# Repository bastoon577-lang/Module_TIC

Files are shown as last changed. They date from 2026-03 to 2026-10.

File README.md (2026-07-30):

<p align="center">
  <!-- Ko-fi badge -->
  <a href="https://Ko-fi.com/bastoon577lang">
    
  </a>

  <!-- Buy Me a Coffee badge -->
  <a href="https://buymeacoffee.com/bastoon577lang">
    
  </a>

  <!-- PayPal badge -->
  <a href="https://www.paypal.com/donate?hosted_button_id=4CDVJA8LLUR78">
    
  </a>
</p>

# Module_TIC
Le Module TIC est un équippement fonctionnant sur plateforme [ESP01](https://www.captain-arduino.fr/esp8266-01s/) capable d'extraire les données issues du bornier TIC du compteur Linky et de les partager/offrir
sur un réseau TCP/IP au travers du WIFI et d'un mécanisme WebSocket.

<div align="center">
  <picture>
    ModuleTIC
  </picture>
</div>

*******
Table des matières
 1. [Mes motivations](#motivation)
 2. [Concept du Module TIC ?](#concept)
 3. [Notice d'utilisation](#useit)
 4. [Reproduction hardware](#hard)
*******

<div id='motivation'/> 

## Mes motivations
Aveugle sur la consommation d'énergie de mon foyer, j'ai souhaité intégrer un mécanisme capable de lire en temps réel les données issues du compteur Linky.
Le but étant par la suite d'effectuer l'asservissement des équipements en foncton de l'énergie disponible de l'installation électrique par le délestage :
 1. De la charge de la voiture électrique,
 2. Du ballon d'eau chaude,
 3. De Miner de bitcoin,
 4. etc...

<div id='concept'/> 

## Concept du Module TIC
Veuillez consulter le [Wiki du projet](https://github.com/bastoon577-lang/Module_TIC/wiki) pour plus d'informations concernant le concept.

<div id='useit'/> 

## Notice d'utilisation
Veuillez consulter la [notice d'utilisation](https://github.com/bastoon577-lang/Module_TIC/blob/main/USER_MANUAL/Notice%20Module%20TIC.pdf) pour plus d'informations.

<div id='hard'/>

## Reproduction hardware

J'ai mis à disposition les sources complètes (BOM, GERBER, etc.) pour la reproduction du PCB ModuleTIC [ici](https://oshwlab.com/sebastiendaligault577/module-tic) que j'ai fait imprimé chez [JLCPCB](https://jlcpcb.com/fr/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).

J'ai du matériel à disposition [ici](https://github.com/bastoon577-lang/Module_TIC/wiki/Fourniture-Hardware) 😉
 
 ###### Auteur : *Sébastien DALIGAULT*.

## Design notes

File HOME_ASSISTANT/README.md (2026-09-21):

# Configurations

> ⚠️ Il existe différents modes de fonctionnement:
> * Le mode Historique (Monophasé ou Triphasés)
> * Le mode Standard (Monophasé ou Triphasés)

## Mode Historique

Utilisez le fichier [Mode_Historique.yml](https://github.com/bastoon577-lang/Module_TIC/blob/main/HOME_ASSISTANT/Mode_Historique.yml)
puis ajoutez/supprimez les données que vous souhaitez remonter en consultant la documentation technique Enedis-MOP-CPT_002E-1.pdf.

## Mode Standard

Utilisez le fichier [Mode_Standard.yml](https://github.com/bastoon577-lang/Module_TIC/blob/main/HOME_ASSISTANT/Mode_Standard.yml)
puis ajoutez/supprimez les données que vous souhaitez remonter en consultant la documentation technique Enedis-MOP-CPT_002E-1.pdf.

#### Auteur : *Sébastien DALIGAULT*.

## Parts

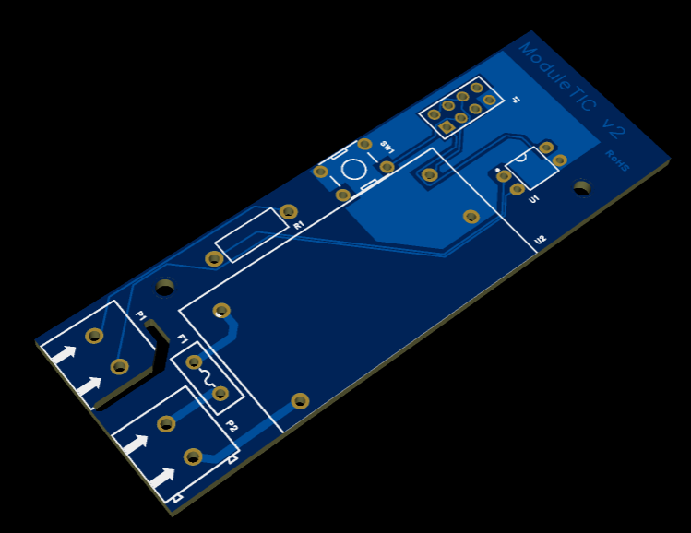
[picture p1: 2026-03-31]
HARDWARE/PCB/PCB_3D_WITHOUT_COMPONENTS.png

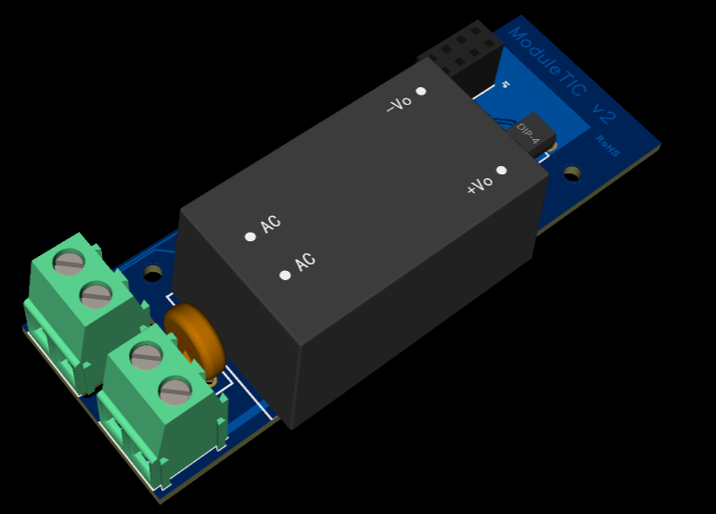
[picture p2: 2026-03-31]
HARDWARE/PCB/PCB_3D_WITH_COMPONENTS.png

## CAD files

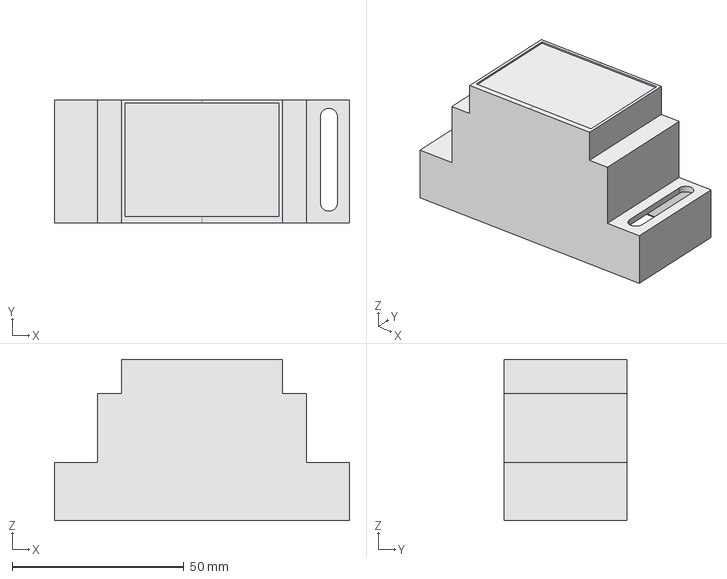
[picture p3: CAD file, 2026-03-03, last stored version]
HARDWARE/PLASTURGIE/Supérieur.FCStd
86.0 x 36.0 x 47.0 mm

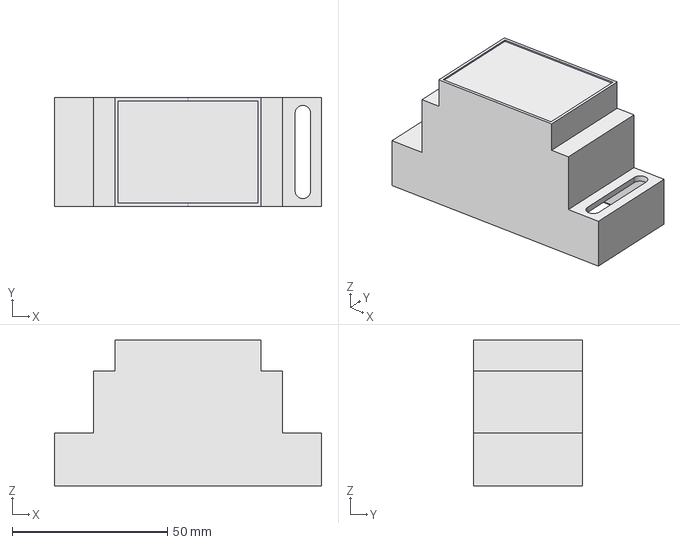
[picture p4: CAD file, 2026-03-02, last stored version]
Module_TIC/HARDWARE/PLASTURGIE/Supérieur.FCStd
86.0 x 35.0 x 47.0 mm

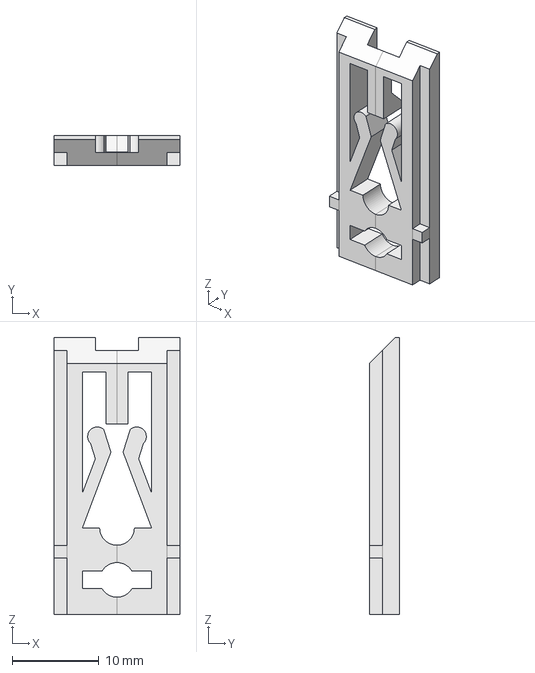
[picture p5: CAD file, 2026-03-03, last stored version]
HARDWARE/PLASTURGIE/Locker.FCStd
14.5 x 3.50 x 32.0 mm

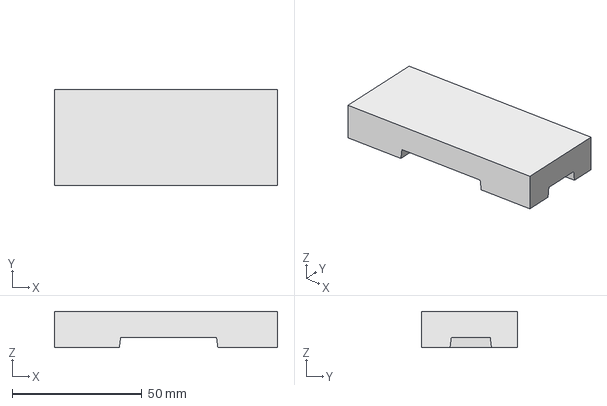
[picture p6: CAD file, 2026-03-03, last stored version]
HARDWARE/PLASTURGIE/Socle.FCStd
86.0 x 37.0 x 14.0 mm

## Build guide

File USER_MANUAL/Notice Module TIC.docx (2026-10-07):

Module_TIC

USER MANUAL

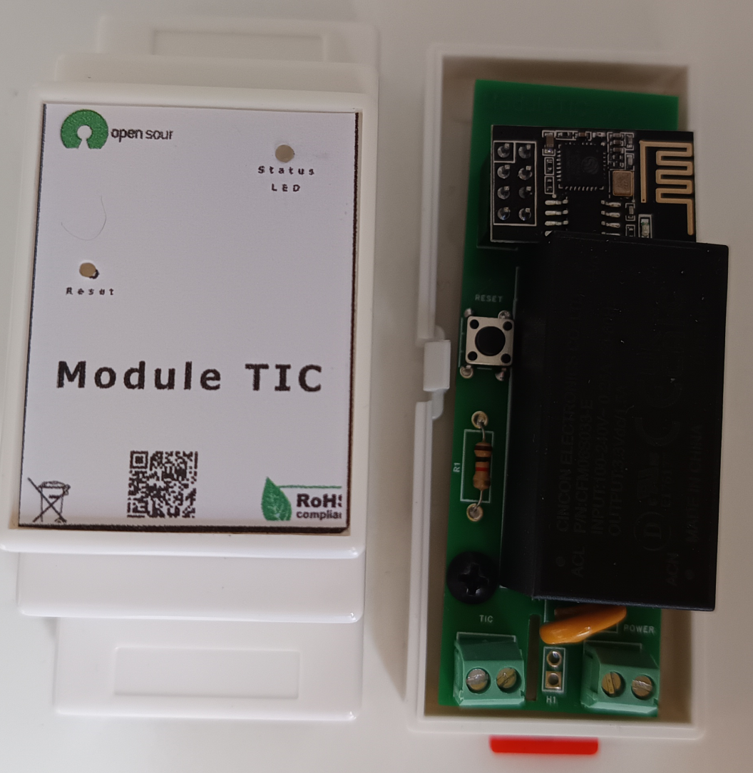
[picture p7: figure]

# Notice d'utilisation

# 1. Présentation du Module TIC

## 1.1. Présentation générale

Le Module TIC (fig.1) est un équipement permettant un suivit de consommation électrique en temps réel par la lecture et la visualisation des données de Télé Informations Client (TIC) issues du compteur intelligent Linky sur le réseau TCP/IP au travers du réseau WIFI.

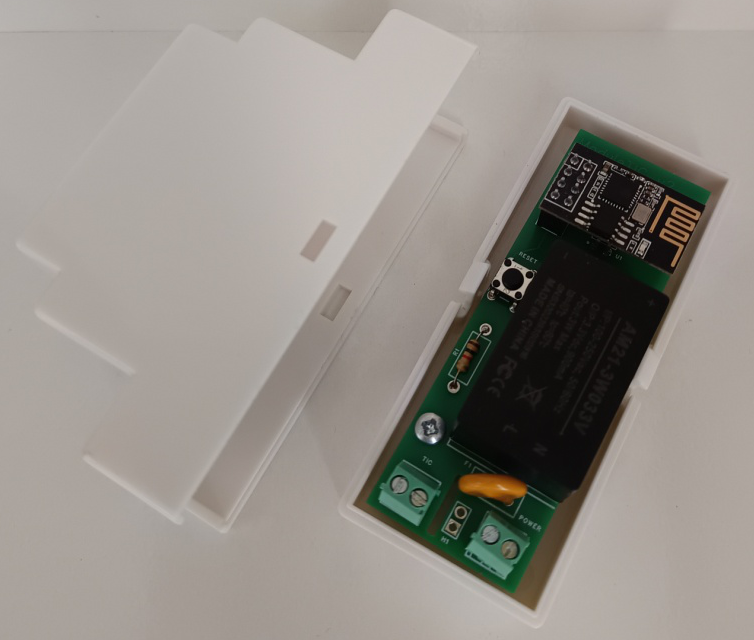
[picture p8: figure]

Figure 1 : Module TIC

Construit autour d'une puce WIFI, l'équipement est un objet connecté qui communique les informations de consommation électrique sur les réseaux informatiques; il dispose d'un :

- Serveur WEB, capable d'interagir avec tous types de terminaux (PC, Tablette, Smartphone, etc.) disposant d'un navigateur WEB.
- Serveur WebSocket, capable d'émettre les données de consommation en temps réel.

Ce dispositif permet une visualisation immédiate des données de consommation mais aussi l'interfaçage d'équipements électriques intelligents capables de réguler leurs puissances sur le réseau électrique en vue de garantir la non disjonction de l'installation par des phénomènes de surcharge.

## 1.2. Câblage

Le Module TIC doit être intégrer sur un rail DIN dans le tableau électrique.

Risque de gravesdommages matériels et de blessures corporelles sérieuses dus, par exemple , au feu ou à un choc électrique ayant pour origine une installation électrique incorrecte.

Seule une personne justifiant de connaissances de base dans les domaines suivants peut assurer une installation électrique sécurisée :

- raccordement aux réseaux d'installation
- raccordement de différents appareils électriques
- pose de câble

Seuls les professionnels compétents ayant été formés dans le domaine de la technologie de l'installation électrique possèdent, en général, ces compétences et cette expérience. Si ces conditions minimum ne sont pas remplies ou ignorées de quelque manière que ce soit, vous serez entièrement responsable en cas de dommages sur des biens ou sur des personnes.

Le Module TIC doit être câblé sur le bornier TIC (I1-I2) du compteur Linky Monophasé (fig.2) ou Triphasé (fig.3) par l'intermédiaire d'un câble en paire torsadée simple avec écran aluminium d'une section de 0,5 mm² et d'une longueur maximum de 500 mètres (Pour plus d'informations, se référer à la note externe Enedis, au chapitre 5.1.2. Caractéristiques du bus de télé-information) et doit être alimenté et protégé par un disjoncteur C2 sur l'installation 220 V CA, 50 Hz (fig.4) du tableau électrique.

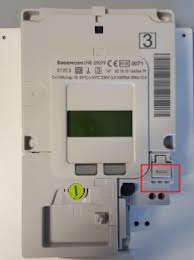
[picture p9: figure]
Téléinformation du compteur Linky | Le blog de Lulu
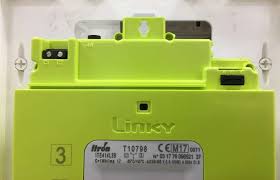
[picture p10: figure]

Figure 2 : Bornier TIC sur compteur Monophasé | Figure 3 : Bornier TIC sur compteur Triphasé

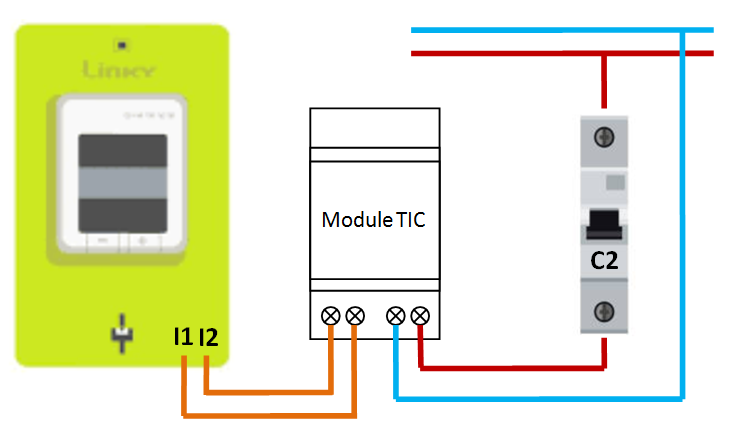
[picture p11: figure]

| Tension nominale : 230V CA, 50 Hz Puissance nominale : < 160 mW Bornes de raccordement : Bornes à vis pour max 2 x 1,5², 0,5 Nm Température ambiante: -10 à 25 °C Protection requise: Disjoncteur 2 A Protocole de communication: 802.11 b/g/n Fréquence de fonctionnement: 80 - 160 MHz
Figure 4 : Schéma de câblage du Module TIC

## 1.3. Diagnostiques visuels

Le Module TIC (fig.5) comporte différents éléments de diagnostique:

- LED Status renseignantde l'étatde fonctionnement de l'équipement,
- Un bouton Reset, permettant une réinitialisation de l'équipement.

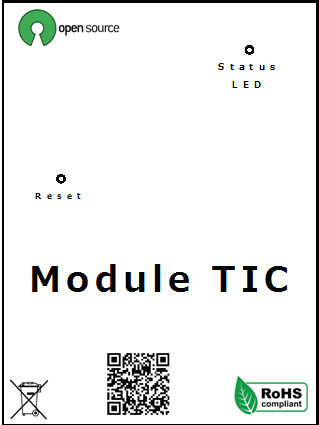
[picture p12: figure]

Figure 5 : Interface Module TIC

Etats de clignotement de la LED Status:

Type de clignotement | Etat
Rapide (5 Hz) | Module TIC en attente d'une configuration
Lent (1 Hz) | Module TIC en fonctionnement standard

Le bouton Resetdoit être pressé pendant 2 secondes pour être effectif, et permettra un retour dans la configuration d'origine de l'équipement.

# 2. Types de configurations WIFI

Le choix du type de configuration est un paramètre crucial lors de l'installation de votre équipement;

Le Module TIC peut utiliser 2 modes de fonctionnement WIFI (Station ou Point d'accès) :

Le mode station (fig.6 & 7) est un mode où le Module TIC est connecté à un hotspot WIFI (Box Internet, répéteur WIFI, etc.) et permet un accès aux données TIC du compteur Linky au travers du réseau WIFI domestique.

Le mode Point d'Accès (fig.8)est un mode où le Module TIC est un hotspot WIFI pouvant accueillir les connexions des terminaux (stations) souhaitant accéder au données TIC du compteur Linky.

Dans la majorités des cas, le Module TIC devra être configuré en mode station et configuré pour être connecté sur un point d'accès WIFI de l'habitatdéjà disponible (BOX Internet, répéteur, etc.); illustré par la figure 6, le Module TIC est installé dans le tableau électriqueimplantédans la zone de couverture WIFI principale de la BOX Internet "SFR_20DA"mais aussi dans celle du WIFI étendue "PLUG_01". Son appairage est donc possible sur l'un ou l'autre en privilégiant le hotspot ayantla puissance maximale.

WIFI étendue
"PLUG_01"

WIFI de la BOX
"SFR_20DA"

Figure 6 : Module TIC intégré en tableau électrique dans la couverture WIFI de la BOX Internet "SFR_20DF" & du WIFI étendue "PLUG_01"

En revanche, la configuration illustrée par la figure 7 montre un Module TIC positionné uniquement dans la zone de couverture de WIFI étendue "PLUG_01" et hors de porté de celle de la BOX Internet "SFR_20DF"; il sera donc nécessaire dans ce contexte d'appairer le Module TIC sur le WIFI étendue "PLUG_01".

WIFI de la BOX
"SFR_20DA"

WIFI étendue
"PLUG_01"

Figure 7 : Module TIC intégré en tableau électrique hors de la couverture WIFI de la BOX Internet "SFR_20DF"

Dans ces deux cas, le Module TIC est connecté sur des point d'accès WIFI du domicileen mode station et peut être consulté par l'intermédiaire de terminaux (Ordinateur, Smartphone, tablette, etc.) sur ce même réseau Local Area Network (LAN).

Le mode point d'accès,moins couramment utilisé, permet l'ouverture d'un hotspot WIFI par le Module TIC lui-même; illustrée par la figure 8, ce mode de fonctionnement sans connexion à un point d'accès WIFI de l'habitatpermet l'installation d'un Module TIC :

- Dans une habitation sans BOX Internet ni point d'accès WIFI,
- Ou tout simplement dé-corrélé du réseau LAN.

Dans ce contexte, le terminal souhaitant consulter les données TIC devra établir une connexion WIFI avec le Module TIC et rester dans la zone de couverture WIFI du Module TIC.

WIFI TIC
"ModuleTIC"

Figure 8 : Module TIC en mode point d'accès

Ce type de configuration est donc la moins appréciée, car elle ne bénéficie pas de la couverture réseau LAN disponible dans le domicile, et implique une procédure de déconnexion du réseau LAN et reconnexion sur le Module TIC pour permettre de consulter les données TIC (fig.9).

WIFI TIC
"ModuleTIC"

WIFI de la BOX
"SFR_20DA"

WIFI étendue
"PLUG_01"

Figure 9 : Module TIC intégré en tableau en mode point d'accès avec un réseau LAN

# 3. Configuration du Module TIC

La configuration du Module TIC doit respecter les préconisations suivantes:

- Le Module TIC doit être sous tension (Clignotement rapide de la LED Status),
- La configuration doit être effectuer avec un terminal positionné dans la zone de couverture WIFI du Module TIC (fig.10) (35 mètres recommandés),
- En configuration Station WIFI(se référer au chapitre 2.), le Module TIC doit être dans la zone de couverture du point d'accès WIFI(BOX, routeur, etc.) (fig.10).

Zone Module TIC

Zone point d'accès (BOX, routeur, etc.)

Terminal de configuration

35 m

Figure 10 : Zone de couverture WIFI

## 3.1. Connexion au Module TIC

Etape | Interface | Remarques

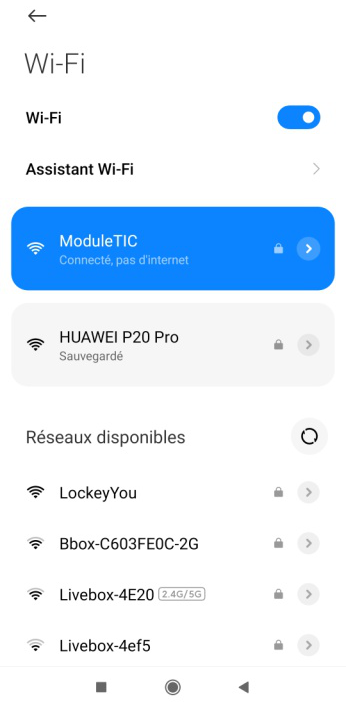
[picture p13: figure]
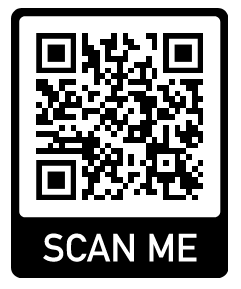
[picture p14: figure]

1 | | Se connecter au WIFI du Module TIC en utilisant le QR-Code suivant: Ou, effectuer une connexion manuelle au WIFI du Module TIC: - Nom du réseau : ModuleTIC - Mot de passe : ModuleTIC - Chiffrement : WPA / WPA2

## 3.2. Configuration du Module TIC

Etape | Interface | Remarques

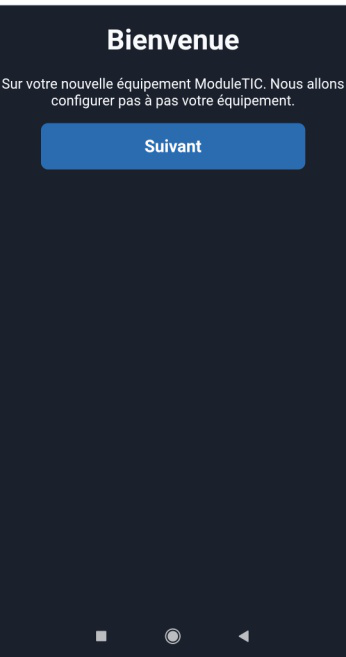
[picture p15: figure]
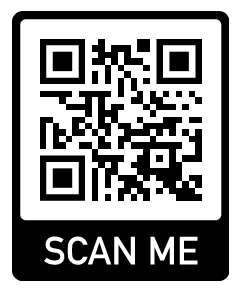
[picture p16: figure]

2 | | La connexion à la page de configuration est automatique, néanmoins, vous pouvez y accéder en utilisant le QR-Code suivant : Ou par l'URL : - http://192.168.4.1 Cliquer sur le bouton Suivant (passer à l'étape 3). Si vous utiliser un Smartphone pour effectuer la configuration du Module TIC, assurez-vous que seul le WIFI est activé; veuillez désactiver les données mobile.

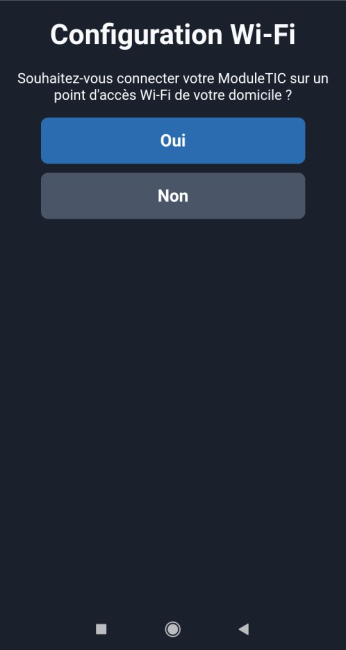
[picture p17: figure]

3 | | Configurer le mode de fonctionnement souhaité en cliquant sur les boutons: - Oui (Mode Station) (passer à l'étape 4.1) - Non (Mode Point d'Accès) (passer à l'étape 5.1) Le mode de fonctionnement est un élément crucial de la configuration du Module TIC, pour plus d'informations concernant les différents modes de fonctionnement WIFI, se référer aux chapitre 2. Types de configurations WIFI du Module TIC.

## 3.2.2. Mode Station WIFI (connexion sur un point d'accès de l'habitat)

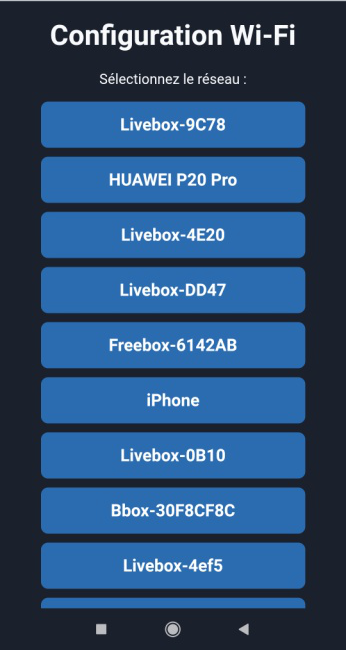
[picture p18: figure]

4.1 | | Sélectionner le nom du réseau souhaité dans la liste des réseaux disponibles (passer à l'étape 4.3). Si le réseau n'est pas visible dans la liste, cliquer sur le bouton Saisie manuelle, puis renseigner le nom du réseau (passer à l'étape 4.2).

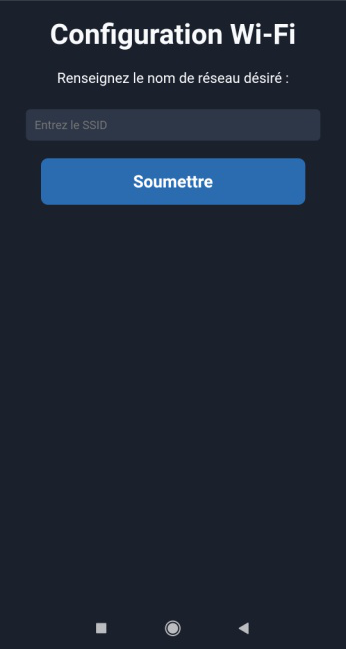
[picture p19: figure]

4.2 | | La Saisie Manuelle permet de renseigner le SSID du réseau qui est caché ou non présent dans la liste des réseaux disponibles. Renseigner le nom du réseau (SSID) souhaité puis cliquer sur le bouton Soumettre(passer à l'étape 4.3).

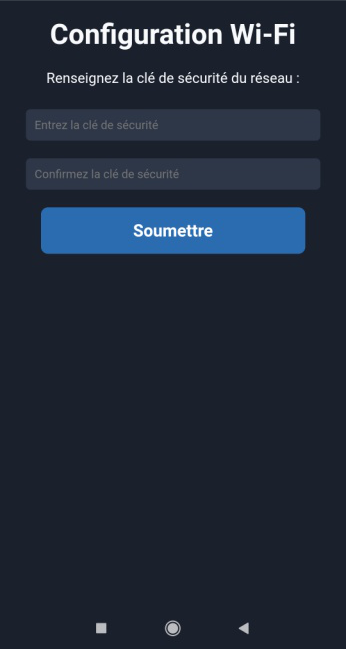
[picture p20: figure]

4.3 | | Renseigner la clé de sécurité du réseau associé puis cliquer sur le bouton Soumettre (passer à l'étape 4.4).

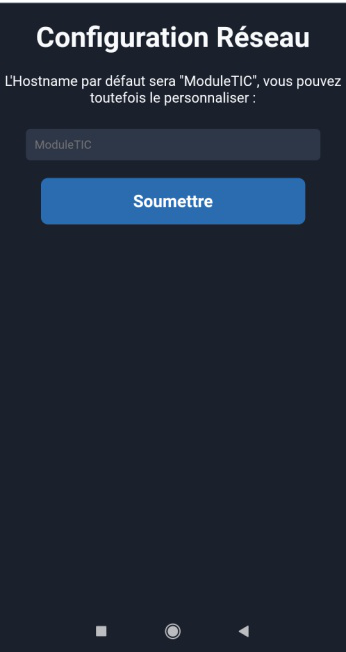
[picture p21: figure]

4.4 | | Renseigner l'Hostname si vous souhaitez le personnaliser puis cliquer sur le bouton Soumettre(passer à l'étape 4.5). Ou simplement cliquer sur le bouton Soumettre si vous souhaitez utiliser celui par défaut(passer à l'étape 4.5). Le nom d'hôte Hostname est un mécanisme permettant d'interroger l'équipement sur le réseau sans connaitre son adresse IP. La configuration par défaut de l'Hostname est "ModuleTIC".

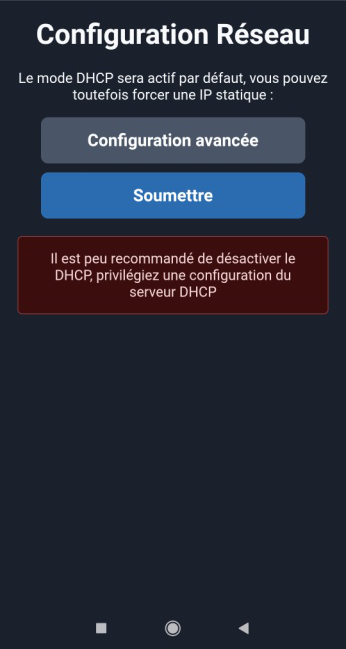
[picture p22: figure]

4.5 | | Cliquer sur le bouton Soumettre si vous souhaitez utiliser une configuration DHCP (passer à l'étape 6). Ou renseigner les champs de configurations avancées: - Adresse IP, - Masque de sous réseau, - Passerelle. Puis cliquer sur le bouton Soumettre (passer à l'étape 6). Il reste néanmoins conseillé d'utiliser la configuration du serveur DHCP de la station WIFI (Box internet, routeur, répéteur, etc.) pour une meilleure fiabilité sur le réseau.

## 3.2.3. Mode Point d'Accès WIFI

Etape | Interface | Remarques

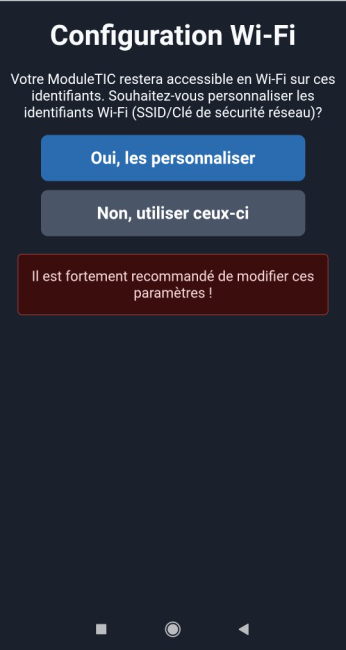
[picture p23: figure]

5.1 | | Le Module TIC est dans la configuration suivante: - Nom du réseau : ModuleTIC - Mot de passe : ModuleTIC - Chiffrement : WPA / WPA2 Cliquer sur le bouton Oui les personnaliser, si vous souhaitez personnaliser ces paramètres (SSID / Mot de passe) (passer à l'étape 5.2). Cliquer sur le bouton Non, utiliser ceux-ci, si vous souhaitez garder cette configuration (passer à l'étape 6). Veiller à bien mémoriser cette nouvelle configuration; un Reset est néanmoins possible à tout moment pour effectuer un retour en configuration d'origine.

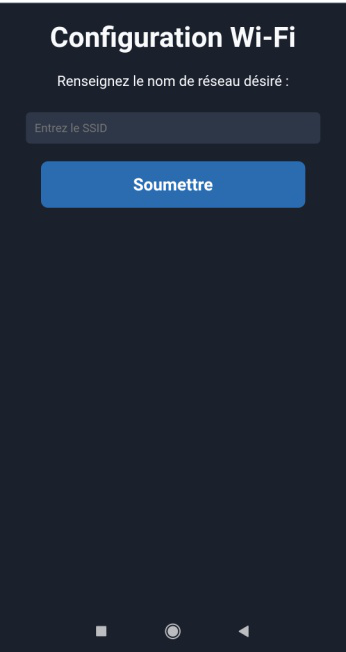
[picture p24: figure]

5.2 | | Renseigner le nom du réseau souhaité puis cliquer sur le bouton Soumettre (passer à l'étape 5.3). Le réseau sera accessible lors du redémarrage du Module TIC.

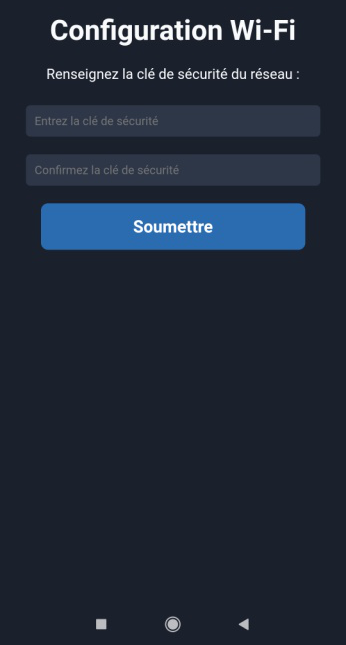
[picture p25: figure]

5.3 | | Renseigner la clé de sécurité souhaitée puis cliquer sur le bouton Soumettre (passer à l'étape 6). Le réseau sera accessible lors du redémarrage du Module TIC.

## 3.2.4 Configuration des ports de services

6 | | Le Module TIC utilise un serveur WEB par défaut sur le port 80 pour être consulté sur le réseau. Il est possible mais peu recommandé de modifier ce port de service. Cliquer sur le bouton : - Oui, utiliser le 80 (pour garder le port par défaut), - Non, le modifier (pour le personnaliser). Le changement du port de service WEB implique l'utilisation explicite de celui-ci à la connexion; le standard WEB utilise le 80, et permet une connexion directe via l'URL : http://ModuleTIC.local Un changement de port (exemple 93), implique l'utilisation de l'URL suivant : http://ModuleTIC.local:93
7 | | Le Module TIC utilise un serveur WEB Socket par défaut sur le port 443 pour permettre l'exposition des données TIC sur le réseau. Il est possible de modifier ce port de service. Cliquer sur le bouton : - Oui, utiliser le 443 (pour garder le port par défaut), - Non, le modifier(pour le personnaliser). Le changement du port de service WEB Socket implique le renseignement de celui-ci sur les équipements souhaitant consulter les données TIC.

## 3.2.5 Configuration du compteur

8 | | Le Module TIC est capable de lire les 2 types de modes exposés par les compteurs (Linky ou numérique). Cliquer sur le bouton : - Historique, - Standard. Il est possible de vérifier sur le compteur Linky le mode utilisé, en navigant dans le menu 'Mode TIC' par l'appuis sur le bouton '+' du compteur. Le mode est lié au compteur, un mauvais choix aura pour conséquence une absence de donnée.

## 3.2.6 Fin de la configuration

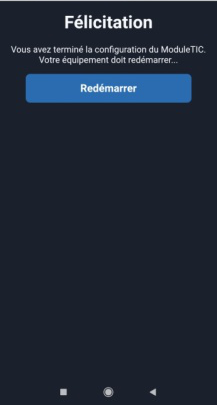
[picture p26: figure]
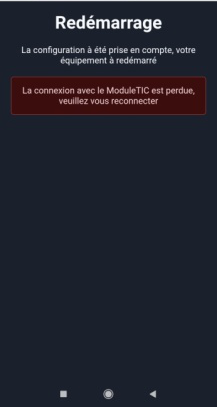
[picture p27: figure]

| La configuration du Module TIC est maintenant terminée. Cliquer sur le bouton Redémarrer pour que la configuration soit prise en compte, cette action à forcer un redémarrage de l'équipement et ainsi fait disparaitre le point d'accès ModuleTIC sur lequel vous étiez connecté. Poursuivez au chapitre suivant 4. Exploitation du Module TIC

# 4. Exploitation du Module TIC au travers de son interface WEB

La connexion au Module TIC diffère en fonction de la configuration WIFI effectuée précédemment. Dans la majorité des cas, en mode station (connecté à un point d'accès WIFI du domicile), la connexion au Module TIC doit être effectuéede la manière suivante:

- Connecter votre terminal (PC, Smartphone, etc.) à votre réseau WIFI,
- Ouvrir un navigateur WEB (Chrome, Firefox, etc.),
- Utiliser les URLs suivantes:
  - http://192.168.x.xxx (Utilisation de l'IP du Module TIC)
  - http://ModuleTIC.local (Utilisation de l'Hostname du Module TIC)*

Dans les cas plus particuliers du mode point d'accès (sans connexion à un point WIFI du domicile), la connexion au Module TIC doit être effectuée de la manière suivante:

- Connecter votre terminal (PC, Smartphone, etc.) à votre réseau WIFI du Module TIC,
- Ouvrir un navigateur WEB (Chrome, Firefox, etc.),
- Utiliser l'URL : http://192.168.4.1.

La gestion de ce protocole est très inégale et est intégré : - A partir de Windows 10 version 1511 sur PC, - A partir des versions 12/13 d'Android. Si votre box internet ou votre routeur le permet, configurez une réservation d'adresse IP (DHCP statique) pour cet équipement et utilisez l'adresse IP directement, ou attribuez-lui un nom d'hôte local (exemple : http://ModuleTIC.home). L'utilisation de l'hostname utilise le protocole mDNS (Multicast DNS), qui permet de résoudre les noms en .local sans serveur DNS dédié. | La page principale rassemble les données TIC temps réel issues du compteur Linky encapsulées par des étiquettes: - ISOUSC : Intensité maximal du contrat - IINST : Intensité absorbée - PAPP : Puissance apparente - ... Les données sont affichées en brutes et encapsulées par l'intermédiaire d'étiquettes explicites. Pour plus d'informations, se référer à la note externe Enedis, au chapitre 6.1.1. Compteurs monophasés ou 6.1.2. Compteurs triphasés.
| Un menu de navigation est présent en haut à gauche et permet d'accéder au différents onglets de navigation du Module TIC: - Données TIC - Filtre de données - Configuration système

L'onglet Filtre de données permet d'appliquer un filtre sur les données TIC présentées dans l'onglet Données TIC.

Les compteurs Linky étant très verbeux, le filtre permet l'affichage des données qui vous semble pertinentes. Son utilisation passe par la réalisation du filtre mentionnant les étiquettes séparées par des ',' par exemple :

IRMS1,PCOUP,LTARF

Le bouton Soumettre permet l'application du filtre.

Le bouton Réinitialiser permet la réinitialisation du filtre.

Le filtre admet une longueur de 128 caractères ',' incluent, et affiche les données dans l'ordre du filtre permettant une meilleure visualisation.
| La page de configuration système permet d'obtenir une visualisation complète de la configuration du Module TIC sur le réseau (IP, MAC, ports, etc.), de la version logiciel et du protocole utilisé (Historique ou Standard). Le bouton Basculer le Thème permet de basculer entre : - Thème sombre - Thème clair Le bouton Retour Usine permet une réinitialisation du Module TIC en configurations d'origines. Le retour en configuration usine à le même effet qu'un appuis sur le bouton Reset, et impose une reconfiguration de l'équipement.

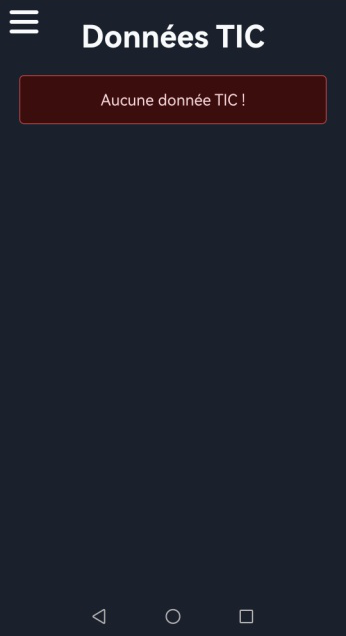
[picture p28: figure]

| Une mauvaise connexion sur le bornier TIC Linky ou le choix du mode (Historique ou Standard) peut entraîner une perte de lecture des données, veillez à ce que le bornier TIC soit bien connecté au compteur Linky et que le mode configuré soit correct. Il est possible de vérifier sur le compteur Linky le mode utilisé, en navigant dans le menu 'Mode TIC' par l'appuis sur le bouton '+' du compteur Linky.

# 5. Lecture des données TIC par un système tiers

Le Module TIC embarque un serveur WebSocket indépendant qui lui permet d'émettre les données de consommation du compteur au travers du réseau TCP/IP. Il est possible de lire ces données en utilisant tout mécanisme WebSocket Client à votre disposition; je mets néanmoins à disposition l'utilitaire WebSocket-Client.exe (fig. 11) disponible à l'URL suivant :

https://github.com/bastoon577-lang/websocket-client/releases

Cet utilitaire permet :

- D'afficher en temps réel les données issues du compteur,
- Filtrer les données utiles,
- Une sauvegarde des données en vue d'une exploitation temporelle ultérieure.

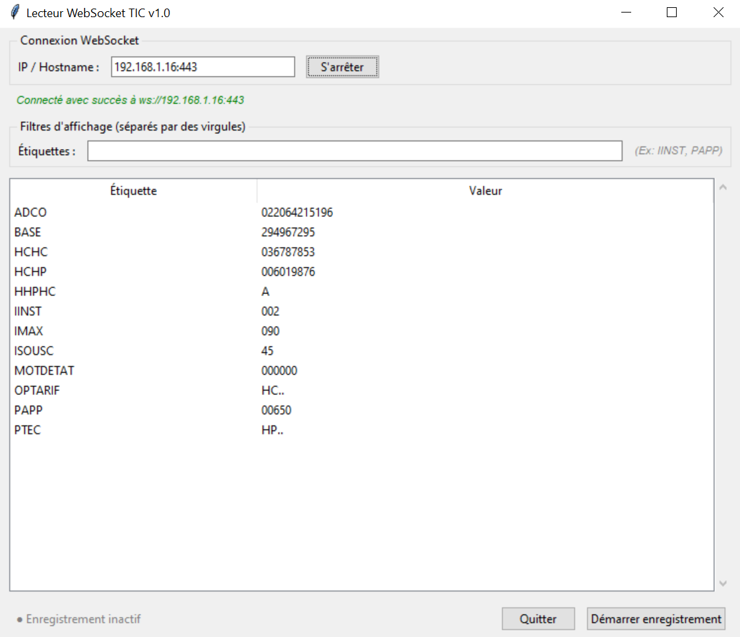
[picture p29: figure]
IHM

Figure 11 : Utilitaire WebSocket-Client.exe

Positionner l'adresse IP ou l'Hosname de votre Module TIC sur le réseau "ModuleTIC.local" puis clique sur Lire. Les données lues seront immédiatement accessibles dans la fenêtre inférieure.

Le filtre d'affichage peut être utilisé par l'écriture d'une (es) étiquette(s) séparé par une ',' (ex: IINST, PAPP).

Le bouton Démarrer l'enregistrement vous permet d'effectuer un enregistrement des données; celles-ci seront enregistrées toutes les secondes, et vous permettra de générer un fichier .csv pouvant être exploité par Excel ou tout autre tableur.

# 6. Migration du Module TIC vers Home Assistant

Le Module TIC peut être rendu compatible pour fonctionner avec l'environnement Home Assistant (https://www.home-assistant.io/), un logiciel gratuit et open-source qui centralise et automatise tous les appareils connectés de la maison sur une seule interface. Vous trouverez la procédure de migration à l'URL suivante :

https://github.com/bastoon577-lang/Module_TIC/wiki/Compatibilité-Home-Assistant

# 7. Mettre à jour le Module TIC

Vous trouverez les différentes versions logicielles à l'adresse des Releases suivante :

https://github.com/bastoon577-lang/Module_TIC/releases

Pourquoi mettre à jour mon équipement:

- Intégration de nouvelles fonctionnalités,
- Correction de bugs.

La version logicielle de votre Module TIC est visible dans Configuration système à l'information Logiciel (fig.12).

Figure 12 : Version logicielle

La procédure de mise à jour de l'équipement est la suivante:

1. Télécharger l'outil OTA_Update.exeà partir de l'URL suivante:

https://github.com/bastoon577-lang/OTA_Updater/releases

2. Télécharger le firmware Module_TIC_vx.bin à partir de l'adresses des Releases,
3. Ouvrir le logiciel OTA_Updater.exe (fig.13) puis:
  a. Positionner le firmware Module_TIC_vx.bin dans le champs fichier,
  b. Positionner l'adresse IP ou l'Hostname dans le champsIP/Hostname,
  c. Cliquer sur le bouton Mettre à jour.

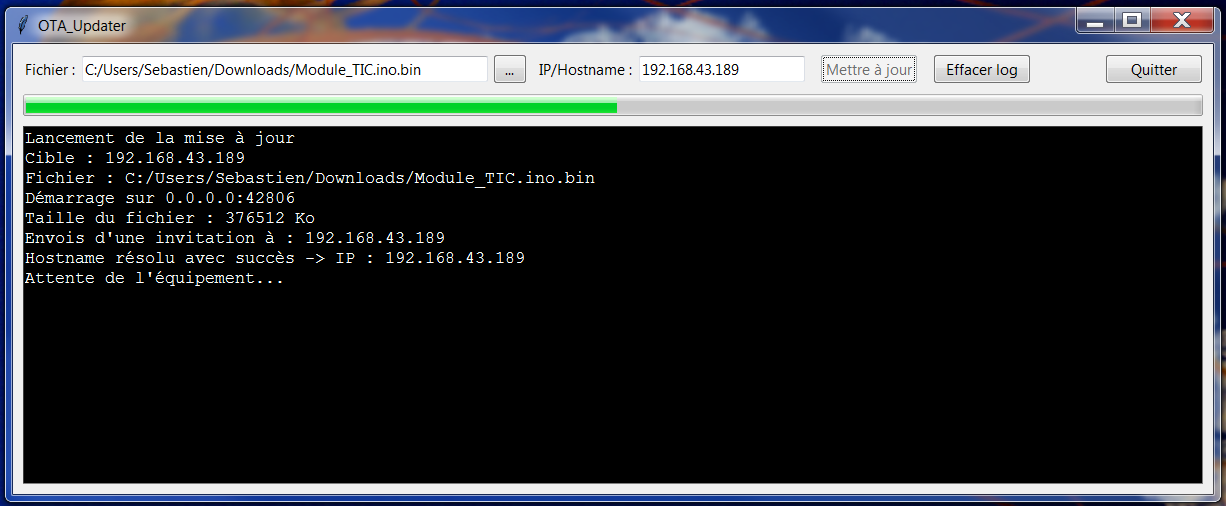
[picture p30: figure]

Figure 13 : Mise à jour du Module_TIC_vx.bin par OTA_Updater.exe

Le Pare Feu Windows peut fortement altérer l'utilitaire de mise à jour OTA_Updater, il est recommandé de désactiver temporairement le Pare Feu Windows, pour effectuer la mise à jour.

# 6. Dépannage

Problème | Cause possible | Solution possible
La LED status ne clignote pas | Le Module TIC n'est pas alimenté Le Module TIC est HS La LED est HS | Alimenter le Module TIC Remplacer le Module TIC Remplacer le Module TIC
La LED status clignote rapidement malgré une configuration | La configuration n'a pas été prise en compte | Recommencer la configuration
Le message "Aucune donnée TIC !" | La connexion entre le Module TIC et le compteur est mauvaise Le mode choisit est le mauvais | Vérifier le connexion Changer de mode

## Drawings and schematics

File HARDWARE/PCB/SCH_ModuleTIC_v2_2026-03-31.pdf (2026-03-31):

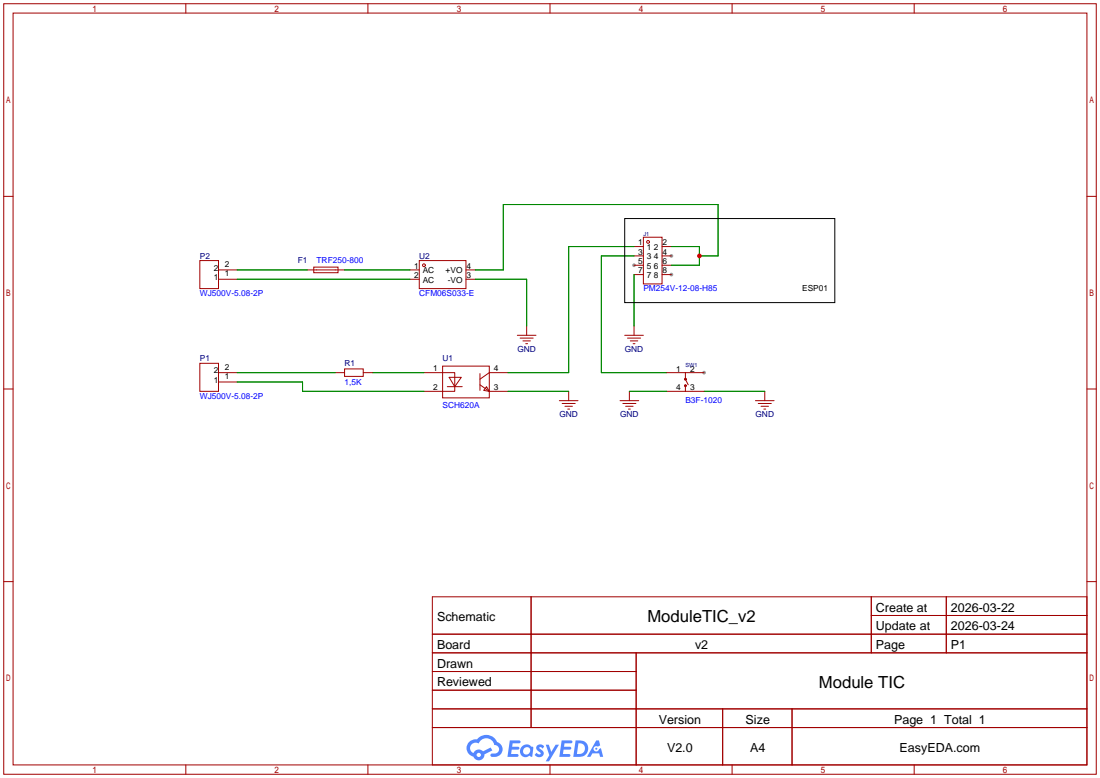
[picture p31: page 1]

Schematic | ModuleTIC_v2 | Create at | 2026-03-22

Update at | 2026-03-24

Board | v2 | Page | P1
Drawn | | Module TIC
Reviewed

Version | Size | Page 1 Total 1
V2.0 | A4 | EasyEDA.com

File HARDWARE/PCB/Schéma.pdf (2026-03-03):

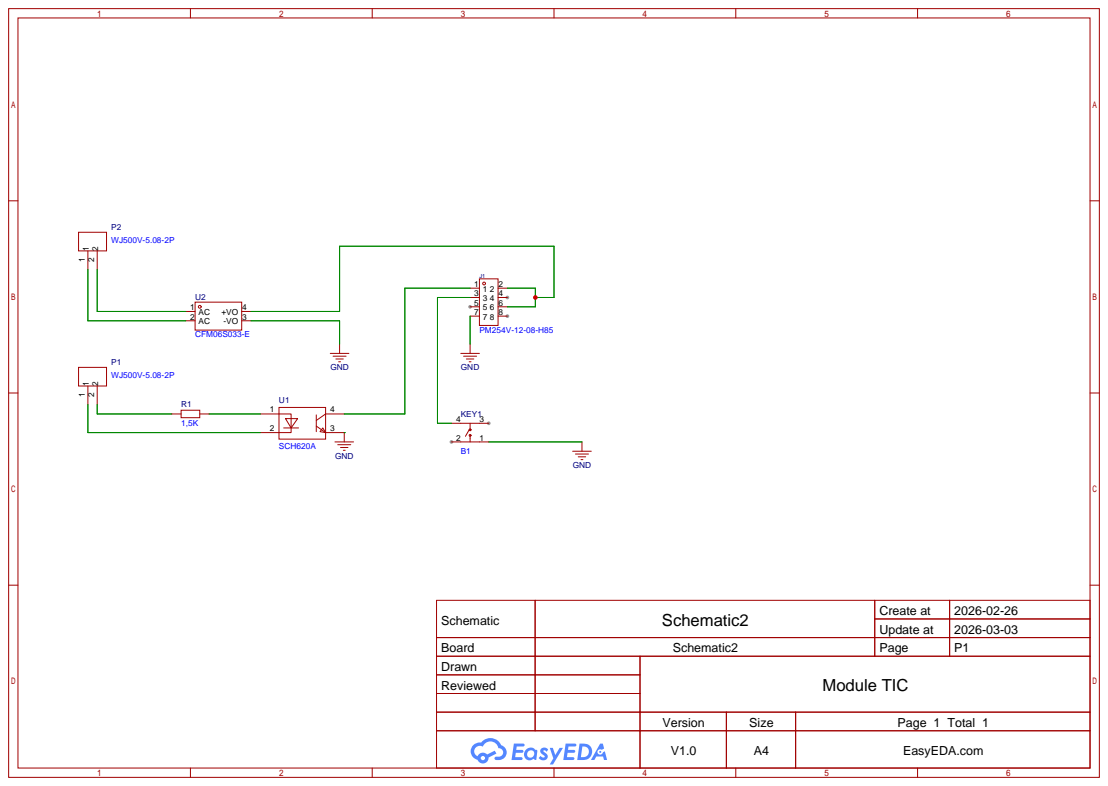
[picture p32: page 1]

Schematic | Schematic2 | Create at | 2026-02-26

Update at | 2026-03-03

Board | Schematic2 | Page | P1
Drawn | | Module TIC
Reviewed

Version | Size | Page 1 Total 1
V1.0 | A4 | EasyEDA.com

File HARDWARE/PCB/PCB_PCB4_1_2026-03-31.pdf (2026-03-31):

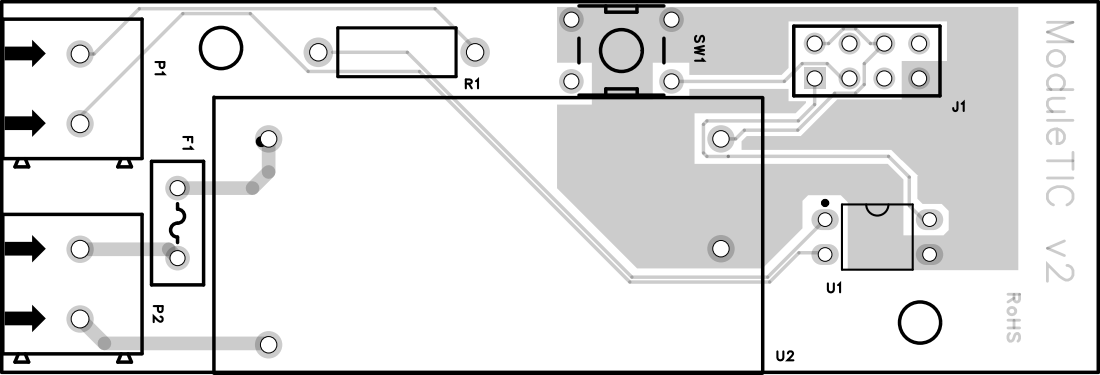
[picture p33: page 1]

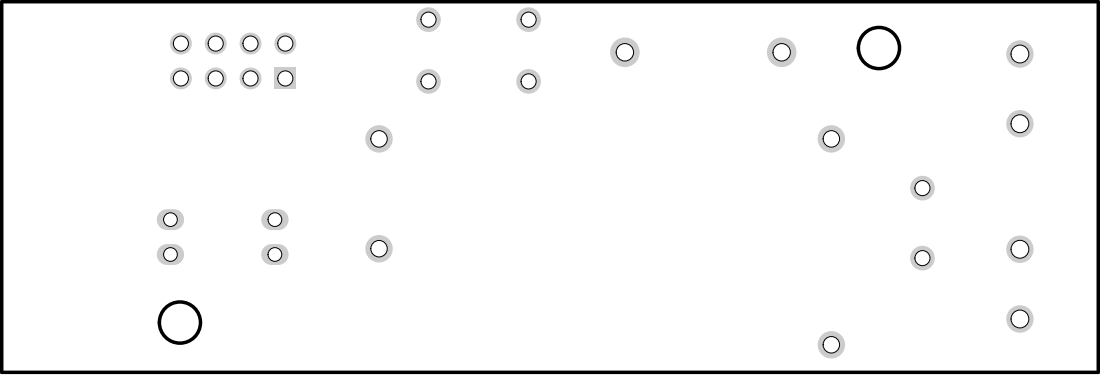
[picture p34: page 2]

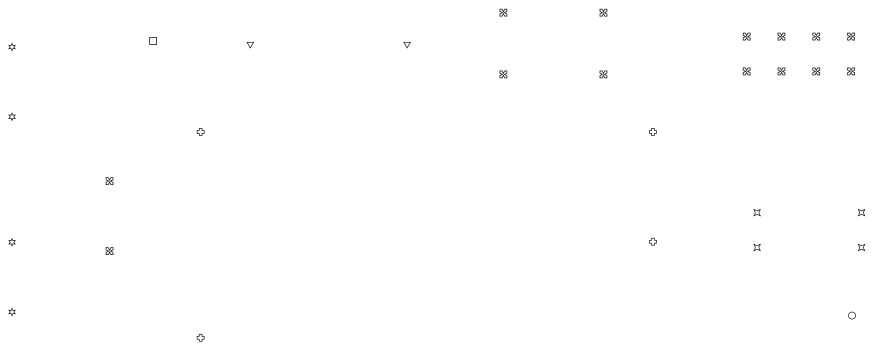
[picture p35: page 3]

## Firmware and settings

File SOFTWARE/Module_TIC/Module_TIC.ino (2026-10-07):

#include <ESP8266WebServer.h>
#include <ArduinoOTA.h>
#include <DNSServer.h>

#include "tic_extract_utils.h"
#include "websocket_utils.h"
#include "eeprom_utils.h"
#include "common_utils.h"
#include "reboot_utils.h"
#include "led_utils.h"

#include "src/ihm_configuration_page.h"
#include "src/ihm_exploitation_page.h"
#include "src/ihm_css_steel_sheet.h"
#include "src/ihm_common.h"

//< Déclaration des variables globales
static VOLATILE_CONF_FIELDS_t volatile_conf;
static STATIC_CONF_FIELDS_t static_conf;
static ESP8266WebServer web_server(0);
static short wifi_equipments;
static DNSServer dns_server;
static TIC_DATA_t tic_data;
static bool dhcp_enable;

/**
 * \fn String ip_stringification(uint8_t *in)
 * \brief Fonction de generation du flux String permettant l'affichage d'une adresse IP
 *        sur le serveur Web
 * \param in le pointeur de l'adresse IP
 * \return le flux String de l'adresse IP
 */
static String ip_stringification(uint8_t *in) {
  return String(in[0]) + '.' + String(in[1]) + '.' + String(in[2]) + '.' + String(in[3]);
}

/**
 * \fn void ip_parser(String in, uint8_t *out)
 * \brief Fonction permettant de parser une adresse IP en éléments uint8_t.
 *        Ce process permet le stockage optimisé d'une IP en mémoire EEPROM
 * \param in, la chaine de caractères IP à formater
 * \param out, le pointeur de sortie
 */
static void ip_parser(String in, uint8_t *out) {
  short index = 0;
  for(short i = 0; i < 4; i++) {
    out[i] = in.substring(index,index + 3).toInt();
    index += 4;
  }
}

/**
 * \fn void erase_eeprom_and_reboot(void)
 * \brief Fonction permettant la suppression des données en mémoire EEPROM
 *        permettant un retour en configuration initiale de l'équippement
 */
static void erase_eeprom_and_reboot(void) {
 // Suppression des données en RAM
  memset(&volatile_conf, 0, sizeof(VOLATILE_CONF_FIELDS_t));
  memset(&static_conf, 0, sizeof(STATIC_CONF_FIELDS_t));
  
  // Sauvegarde des données en mémoire EEPROM
  eeprom_write_data(&volatile_conf,EEPROM_VOLATILE_CFG);
  eeprom_write_data(&static_conf,EEPROM_STATIC_CFG);

  // Redémarrage de l'équippement pour la prise en compte
  reboot_set();
}

/**
 * \fn void send_content_chunked(const char* p, bool isProgmem = true, size_t chunkSize = 512)
 * \brief Fonction permettant de splitter une chaîne de caractère (RAM ou PROGMEM) au serveur Web par morceaux.
 * \param in, Le pointeur vers la chaine de caractères
 * \param in, is_progmem lorsque la données est en mémoire Flash (PROGMEM / FPSTR / F()) (En PROGMEM par défaut)
 * \param in, chunk_size la taille des blocs à envoyer (512 octets par défaut)
 */
static void send_content_chunked(const char* p, bool is_progmem = true, size_t chunk_size = 512) {
  if (!p) return;

  size_t len=(is_progmem)?strlen_P(p):strlen(p);
  char buffer[chunk_size];

  for(size_t i=0;i<len;i+=chunk_size) {
    size_t chunk=((len-i)<chunk_size)?(len-i):chunk_size;
    
    if(is_progmem) {
      memcpy_P(buffer,p+i,chunk);
      web_server.sendContent(buffer,chunk);
    } else {
      web_server.sendContent(p+i,chunk);
    }
  }
}

/**
 * \fn void html_generate_exploitation_page(void)
 * \brief Fonction de generation du flux HTML/CSS/JS pour la page d'exploitation.
 */
static void html_generate_exploitation_page(void) {
  char buf[128];
  web_server.setContentLength(CONTENT_LENGTH_UNKNOWN);
  
  // En-tête et styles HTML
  send_content_chunked((const char*)htmlHeader, true);
  web_server.sendContent(F("<style>"));
  send_content_chunked((const char*)cssSteelSheet, true);
  web_server.sendContent(F("</style>\n</head>\n<body>"));
  send_content_chunked((const char*)htmlPageExploit, true);
  
  // Début des scripts
  web_server.sendContent(F("  <script>"));
  if (!volatile_conf.theme) {
    web_server.sendContent(F("\n  document.body.classList.add('theme-dark');\n"));
  }
  send_content_chunked((const char*)scriptsCommon, true);
  send_content_chunked((const char*)scriptsPageExploit, true);

  // Données TIC
  if (tic_data._nb_elem) {
    web_server.sendContent(F("    createTable(\"tab1\");\n"));
    for (uint8_t i = 0; i < tic_data._nb_elem; i++) {
      snprintf(buf, sizeof(buf), "    addTableLinkyData(\"tab1\",\"%s\",\"--\");\n", tic_data.etiquette[i]);
      web_server.sendContent(buf);
    }
  } else {
    web_server.sendContent(F("    document.getElementById(\"tab1\").innerHTML = '<p class=\"alert\">Aucune donnée TIC !</p>';\n"));
  }
  
  // Données Générales (Réseau & Système)
  web_server.sendContent(F("    createTable(\"tab2\");\n"));
  
  snprintf(buf, sizeof(buf), "    addTableRow(\"tab2\",\"Logiciel\",\"%s\");\n", V_LOGICIEL);
  web_server.sendContent(buf);
  
  snprintf(buf, sizeof(buf), "    addTableRow(\"tab2\",\"Mode\",\"%s\");\n", static_conf.is_standard_mode ? "Standard" : "Historique");
  web_server.sendContent(buf);
  
  snprintf(buf, sizeof(buf), "    addTableRow(\"tab2\",\"DHCP\",\"%s\");\n", dhcp_enable ? "Actif" : "Inactif");
  web_server.sendContent(buf);
  
  snprintf(buf, sizeof(buf), "    addTableRow(\"tab2\",\"Hostname\",\"%s\");\n", static_conf.Hostname);
  web_server.sendContent(buf);
  
  snprintf(buf, sizeof(buf), "    addTableRow(\"tab2\",\"MAC\",\"%s\");\n", WiFi.macAddress().c_str());
  web_server.sendContent(buf);
  
  // Calcul et mise en forme IPv4
  const uint8_t defaultAdr[4] = {192, 168, 4, 1};
  String ip_str = (!static_conf.is_wifi_network_used) 
                  ? ip_stringification((uint8_t*)defaultAdr) 
                  : (dhcp_enable ? WiFi.localIP().toString() : ip_stringification(static_conf.address));
  snprintf(buf, sizeof(buf), "    addTableRow(\"tab2\",\"IPv4\",\"%s\");\n", ip_str.c_str());
  web_server.sendContent(buf);
  
  // Calcul et mise en forme Masque de sous-réseau
  const uint8_t defaultSub[4] = {255, 255, 255, 0};
  String mask_str = (!static_conf.is_wifi_network_used) 
                    ? ip_stringification((uint8_t*)defaultSub) 
                    : (dhcp_enable ? WiFi.subnetMask().toString() : ip_stringification(static_conf.subnet));
  snprintf(buf, sizeof(buf), "    addTableRow(\"tab2\",\"Masque de sous réseau\",\"%s\");\n", mask_str.c_str());
  web_server.sendContent(buf);
  
  // Calcul et mise en forme Passerelle
  const uint8_t defaultGat[4] = {192, 168, 4, 1};
  String gw_str = (!static_conf.is_wifi_network_used) 
                  ? ip_stringification((uint8_t*)defaultGat) 
                  : (dhcp_enable ? WiFi.gatewayIP().toString() : ip_stringification(static_conf.gateway));
  snprintf(buf, sizeof(buf), "    addTableRow(\"tab2\",\"Passerelle par défaut\",\"%s\");\n", gw_str.c_str());
  web_server.sendContent(buf);
  
  // Ports Web et WebSocket
  snprintf(buf, sizeof(buf), "    addTableRow(\"tab2\",\"Port Web\",\"%u\");\n", static_conf.port);
  web_server.sendContent(buf);
  
  snprintf(buf, sizeof(buf), "    addTableRow(\"tab2\",\"Port WebSocket\",\"%u\");\n", static_conf.portWs);
  web_server.sendContent(buf);
  
  // Init WebSocket
  snprintf(buf, sizeof(buf), "    initWebSocket(%u);\n", static_conf.portWs);
  web_server.sendContent(buf);

  // Filtre de données de la table
  snprintf(buf, sizeof(buf), "    updateTableDisplay('tab1','%s');\n", volatile_conf.ihm_filter);
  web_server.sendContent(buf);

  // Fin de page
  web_server.sendContent(F("  };\n"));
  send_content_chunked((const char*)scriptsPageExploitExtend, true);
  web_server.sendContent(F("  </script>\n</body>\n</html>"));
}

/**
 * \fn void html_generate_configuration_page(void)
 * \brief Fonction de generation du flux HTML/CSS/JS pour la page de configuration.
 */
static void html_generate_configuration_page(void) {
  char buf[96];
  web_server.setContentLength(CONTENT_LENGTH_UNKNOWN);
  
  // En-tête HTML et styles
  send_content_chunked((const char*)htmlHeader, true);
  web_server.sendContent(F("<style>"));
  send_content_chunked((const char*)cssSteelSheet, true);
  web_server.sendContent(F("</style>\n</head>\n<body>"));
  
  // Structure principale HTML
  send_content_chunked((const char*)htmlPageConfig, true);
  
  // Début des scripts
  web_server.sendContent(F("  <script>\n  document.body.classList.add('theme-dark');\n"));
  send_content_chunked((const char*)scriptsCommon, true);
  send_content_chunked((const char*)scriptsPageConfig, true);
  
  for (uint8_t i = 0; i < wifi_equipments; i++) {
    snprintf(buf, sizeof(buf), "  addWifiSpot(\"%s\");\n", WiFi.SSID(i).c_str());
    web_server.sendContent(buf);
  }
  
  // Fin de la page
  web_server.sendContent(F("  </script>\n</body>\n</html>"));
}

/**
 * \fn void handle_action_exploitation_button(void)
 * \brief Fonction permettant la gestion des input de type BOUTON des requetes POST en mode exploitation.
 */
static void handle_action_exploitation_button(void) {
  String post_data = web_server.arg("data");
  if(post_data.endsWith("theme"))
    volatile_conf.theme = !volatile_conf.theme;
  else if(post_data.endsWith("reset"))
    erase_eeprom_and_reboot();
    
  // Sauvegarde de la configuration en mémoire EEPROM, ceci n'est pas optimisé car chaque modification entraine une ecriture !
  eeprom_write_data(&volatile_conf,EEPROM_VOLATILE_CFG);  

  web_server.send(200,F("text/html"),"");
}

/**
 * \fn void handle_action_exploitation_input(void)
 * \brief Fonction permettant la gestion des input de type TEXT des requetes POST en mode exploitation.
 */
static void handle_action_exploitation_input(void) {
  if(web_server.arg("filtr").length() > 0)
    strncpy(volatile_conf.ihm_filter,web_server.arg("filtr").c_str(),sizeof(volatile_conf.ihm_filter)-1);
  
  // Sauvegarde de la configuration en mémoire EEPROM, ceci n'est pas optimisé car chaque modification entraine une ecriture !
  eeprom_write_data(&volatile_conf,EEPROM_VOLATILE_CFG);

  web_server.send(200,F("text/html"),"");
}

/**
 * \fn void handle_action_configuration_button(void)
 * \brief Fonction permettant la gestion des input de type BOUTON des requetes POST en mode configuration.
 */
static void handle_action_configuration_button(void) {
  String post_data = web_server.arg("data");
  uint8_t conf = post_data.charAt(3)-'0';
  if(post_data.startsWith("wif"))
    static_conf.is_wifi_network_used = (conf)?1:0;
  else if(post_data.startsWith("mod"))
    static_conf.is_standard_mode = (conf)?1:0;
  else if(post_data.endsWith("end"))                                    // Signal de fin de configuration
  {
    static_conf.is_configured = 1;                                      // Positionnement du flag de configuration
    eeprom_write_data(&static_conf,EEPROM_STATIC_CFG);                  // Sauvegarde des données en mémoire EEPROM
    reboot_set();                                                       // Redémarrage de l'équippement pour la prise en compte
  }
  web_server.send(200,F("text/html"),"");
}

/**
 * \fn void handle_action_configuration_input(void)
 * \brief Fonction permettant la gestion des input de type TEXT des requetes POST en mode configuration.
 */
static void handle_action_configuration_input(void) {
  if(web_server.arg("ssid").length() > 0)
    strncpy(static_conf.SmSsid,web_server.arg("ssid").c_str(),sizeof(static_conf.SmSsid)-1);
  else if(web_server.arg("pass").length() > 0)
    strncpy(static_conf.SmPass,web_server.arg("pass").c_str(),sizeof(static_conf.SmPass)-1);
  else if(web_server.arg("hot1").length() > 0)
    strncpy(static_conf.Hostname,web_server.arg("hot1").c_str(),sizeof(static_conf.Hostname)-1);
  else if(web_server.arg("por1").length() > 0)
    static_conf.port = web_server.arg("por1").toInt();
  else if(web_server.arg("por2").length() > 0)
    static_conf.portWs = web_server.arg("por2").toInt();
  else if(web_server.arg("ip").length() > 0) {
    if(web_server.arg("ip").length() == 15)
      ip_parser(web_server.arg("ip"),static_conf.address);
    if(web_server.arg("mask").length() == 15)
      ip_parser(web_server.arg("mask"),static_conf.subnet);
    if(web_server.arg("gateway").length() == 15)
      ip_parser(web_server.arg("gateway"),static_conf.gateway);
  }
  web_server.send(200,F("text/html"),"");
}

void setup() {
  const uint8_t null_ip[4] = {0,0,0,0};                                 // Vecteur d'IP NULL
  dhcp_enable = 0;

  hal_init();                                                           // Initialisationd de la HAL
  reboot_init(TIMEOUT_REBOOT);                                          // Initialisation du service REBOOT
  eeprom_init();                                                        // Initialisation du service EEPROM
                                                                        // Initialisation des structures en RAM à 0
  memset(&volatile_conf, 0, sizeof(VOLATILE_CONF_FIELDS_t));
  memset(&static_conf, 0, sizeof(STATIC_CONF_FIELDS_t));
  memset(&tic_data, 0, sizeof(TIC_DATA_t));
                                                                        // Initialisation des structures des données issues de la mémoire EEPROM
  eeprom_read_data(&static_conf,EEPROM_STATIC_CFG);
  eeprom_read_data(&volatile_conf,EEPROM_VOLATILE_CFG);
                                                                        // La configuration réseau du SmartCharger est-elle DHCP ?
  if(memcmp(&static_conf.address,null_ip,4) == 0 && 
     memcmp(&static_conf.subnet,null_ip,4)  == 0 && 
     memcmp(&static_conf.gateway,null_ip,4) == 0)
    dhcp_enable = 1;

  if(static_conf.is_configured)                                         // L'equipement est-il configuré ?
  {
    if(static_conf.is_wifi_network_used)                                // Un reseau Wifi est-il configuré ?
    {
      if(!dhcp_enable)                                                  // Une configuration manuelle est presente ?
        WiFi.config(static_conf.address,static_conf.gateway,static_conf.subnet); // Application de la configuration                                 
      WiFi.begin(static_conf.SmSsid,static_conf.SmPass);                // Connexion au réseau
    }
    else                                                                // Aucun reseau Wifi n'est configué
    {
      WiFi.mode(WIFI_AP);                                               // Forçage en mode Access Point
      WiFi.softAP(static_conf.SmSsid,static_conf.SmPass,AP_CHANNEL,AP_VISIBILITE,AP_MAX_EXPL_CONN); // Creation du Hotspot ModuleTIC
    }

    // Initialisation de la page d'exploitation
    web_server.on("/", HTTP_GET, []() {
      html_generate_exploitation_page();
    });
    web_server.on("/theme",HTTP_POST,handle_action_exploitation_button);
    web_server.on("/reset",HTTP_POST,handle_action_exploitation_button);
    web_server.on("/filtr",HTTP_POST,handle_action_exploitation_input);

    tic_extract_init(&tic_data,static_conf.is_standard_mode);           // Initialisation du service TIC_EXTRACT
    ws_server_init(static_conf.portWs,&tic_data);                       // Initialisation du service WebSocket Server
    hal_uart_init(static_conf.is_standard_mode);                        // Initialisation de l'UART
    led_init(TIMEOUT_LED_LENT);                                         // Clignotement lent de la LED
  }
  else                                                                  // L'equipement est vierge
  {
    IPAddress ap_ip(192,168,4,1);                                       // Forçage de l'IP AP en 192.168.4.1
	  WiFi.mode(WIFI_AP);		 											                        // Forçage en mode Access Point
    WiFi.softAPConfig(ap_ip,ap_ip,IPAddress(255,255,255,0));            // Configuration de l'AP
    WiFi.softAP(AP_SSID,AP_PASS,AP_CHANNEL,AP_VISIBILITE,AP_MAX_CONF_CONN); // Creation du Hotspot ModuleTIC
    
	  dns_server.start(AP_DNS_CAPTIVE_PORTAL,"*",ap_ip);        					// Démarrage du serveur DNS (Redirige * vers l'IP de l'AP)
	
    memcpy(&static_conf.Hostname,AP_SSID,sizeof(AP_SSID));              // Sauvegarde du Hostname par defaut
    memcpy(&static_conf.SmSsid,AP_SSID,sizeof(AP_SSID));                // Sauvegarde du SSID par defaut
    memcpy(&static_conf.SmPass,AP_PASS,sizeof(AP_PASS));                // Sauvegarde du Password par defaut
    static_conf.portWs = 443;                                           // Sauvegarde du Port WebSocket par defaut
    static_conf.port   = 80;                                            // Sauvegarde du Port Web par defaut

    // Initialisation de la page de configuration
    web_server.on("/", HTTP_GET, []() {
      html_generate_configuration_page();
    });
    web_server.on("/wif0",HTTP_POST,handle_action_configuration_button);
    web_server.on("/wif1",HTTP_POST,handle_action_configuration_button);
    web_server.on("/mod0",HTTP_POST,handle_action_configuration_button);
    web_server.on("/mod1",HTTP_POST,handle_action_configuration_button);
    web_server.on("/adv0",HTTP_POST,handle_action_configuration_input);
    web_server.on("/hot1",HTTP_POST,handle_action_configuration_input);
    web_server.on("/ssi1",HTTP_POST,handle_action_configuration_input);
    web_server.on("/pas1",HTTP_POST,handle_action_configuration_input);
    web_server.on("/por1",HTTP_POST,handle_action_configuration_input);
    web_server.on("/por2",HTTP_POST,handle_action_configuration_input);
    web_server.on("/end",HTTP_POST,handle_action_configuration_button);
	
	  // Redirection des requêtes de détection de portail captif
	  web_server.onNotFound([]() {
      web_server.sendHeader("Location","http://192.168.4.1/",true);
      web_server.send(302,"text/plain","");
    });

    wifi_equipments = WiFi.scanNetworks();                              // Scan des reseaux Wifi disponibles
    led_init(TIMEOUT_LED_RAPI);                                         // Clignotement rapide de la LED
  }

  ArduinoOTA.setHostname(static_conf.Hostname);                         // Initialisation du Hostname OTA
  WiFi.hostname(static_conf.Hostname);                                  // Initialisation du Hostname Web
  web_server.begin(static_conf.port);                                   // Activation du serveur Web
  ArduinoOTA.begin();                                                   // Activation du service OTA
}

void loop() {
  static unsigned long timer_scan_network = millis();

  if(!static_conf.is_configured) {                                      // L'équippement n'est pas configuré
    dns_server.processNextRequest();                                    // Traitement des requêtes DNS du portail captif
    if(millis() - timer_scan_network >= TIMEOUT_SCAN_NETWORK) {
      WiFi.scanDelete();                                                // Libération du buffer de scan
      wifi_equipments = WiFi.scanNetworks();                            // Scan des reseaux Wifi disponibles
      timer_scan_network = millis();
    }  
  } else {                                                              // L'équipement est configuré
    if(reboot_get_button_state() == true)                               // Le bouton Reset est appuyé
      erase_eeprom_and_reboot();
    tic_extract_handler();                                              // Handler du service TIC_EXTRACT
    ws_handler();                                                       // Handler du service WebSocket
  }
  
  // Néanmoins, dans tous les cas, il est nécessaire d'effectuer les services suivants ...
  web_server.handleClient();                                            // Handler du service Web
  ArduinoOTA.handle();                                                  // Handler du service OTA
  reboot_handler();                                                     // Handler du service REBOOT
  led_handler();                                                        // Handler du service LED
}

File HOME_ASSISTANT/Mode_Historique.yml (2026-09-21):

# Board: Generic ESP8266 Board (Generic)
# Definition: definitions/boards/generic-esp8266/manifest.yaml

esphome:
  name: moduletic
  friendly_name: moduletic

esp8266:
  board: esp01_1m

# logger désactivé sur le port série car GPIO3 (RX) sert au Linky
logger:
  baud_rate: 0 # Désactive l'écriture sur le port série (RX/TX)

api:
  encryption:
    key: "nSN3O2k2vJQF/manp1gNaaKbBh+/YFRb8zR41Hzk0a0="

ota:
  - platform: esphome

# ==========================================
#  SERVEUR WEB EMBARQUÉ
# ==========================================

web_server:
  port: 80

# ==========================================
#  CONFIGURATION WI-FI ET GESTION DES CLIGNOTEMENTS
# ==========================================

wifi:
  ssid: !secret wifi_ssid
  password: !secret wifi_password
  ap:
    ssid: ModuleTIC
    password: ModuleTIC
  on_connect:
    then:
      - lambda: |-
          id(clignotement_interval).stop_poller();
          id(clignotement_interval).set_update_interval(1000);
          id(clignotement_interval).start_poller();
  on_disconnect:
    then:
      - lambda: |-
          id(clignotement_interval).stop_poller();
          id(clignotement_interval).set_update_interval(250);
          id(clignotement_interval).start_poller();

captive_portal:

# ==========================================
#  CONFIGURATION TÉLÉINFO LINKY (HISTORIQUE)
# ==========================================

uart:
  id: uart_bus
  rx_pin:
    number: GPIO3
    mode:
      input: true
  baud_rate: 1200
  data_bits: 7
  parity: EVEN
  stop_bits: 1

# Composant Téléinfo
teleinfo:
  id: myteleinfo
  historical_mode: true
  update_interval: 500ms

# --- Capteurs Numériques ---
sensor:
  - platform: teleinfo
    tag_name: "PAPP"
    name: "PAPP"
    unit_of_measurement: "VA"
    device_class: "apparent_power"
    icon: mdi:flash

  - platform: teleinfo
    tag_name: "HCHP"
    name: "HCHP"
    unit_of_measurement: "Wh"
    device_class: "energy"
    state_class: "total_increasing"

  - platform: teleinfo
    tag_name: "HCHC"
    name: "HCHC"
    unit_of_measurement: "Wh"
    device_class: "energy"
    state_class: "total_increasing"

# Cas du compteur Monophasé
  - platform: teleinfo
    tag_name: "IINST"
    name: "IINST"
    unit_of_measurement: "A"
    icon: mdi:current-ac

# Cas du compteur Triphasés    
#  - platform: teleinfo
#    tag_name: "IINST1"
#    name: "IINST1"
#    unit_of_measurement: "A"
#    icon: mdi:current-ac

#  - platform: teleinfo
#    tag_name: "IINST2"
#    name: "IINST2"
#    unit_of_measurement: "A"
#    icon: mdi:current-ac

#  - platform: teleinfo
#    tag_name: "IINST3"
#    name: "IINST3"
#    unit_of_measurement: "A"
#    icon: mdi:current-ac

  - platform: teleinfo
    tag_name: "IMAX"
    name: "IMAX"
    unit_of_measurement: "A"
    icon: mdi:current-ac

  - platform: teleinfo
    tag_name: "ISOUSC"
    name: "ISOUSC"
    unit_of_measurement: "A"
    icon: mdi:current-ac

# --- Capteurs Texte ---
text_sensor:
  - platform: teleinfo
    tag_name: "ADCO"
    name: "ADCO"
    icon: mdi:identifier

  - platform: teleinfo
    tag_name: "OPTARIF"
    name: "OPTARIF"
    icon: mdi:file-document-outline

  - platform: teleinfo
    tag_name: "PTEC"
    name: "PTEC"
    icon: mdi:clock-outline

  - platform: teleinfo
    tag_name: "HHPHC"
    name: "HHPHC"
    icon: mdi:clock-check-outline

  - platform: teleinfo
    tag_name: "MOTDETAT"
    name: "MOTDETAT"
    icon: mdi:information-outline

# ==========================================
#  BOUTON DE RESET WI-FI SUR GPIO0
# ==========================================

binary_sensor:
  - platform: gpio
    pin:
      number: GPIO0
      mode:
        input: true
        pullup: false
      inverted: false
    name: "Bouton Reset Wifi"
    internal: true
    on_press:
      then:
        - lambda: |-
            esphome::wifi::global_wifi_component->save_wifi_sta("", "");
        - button.press: reboot_button

button:
  - platform: restart
    id: reboot_button
    name: "Redémarrer"
    internal: true

# ==========================================
#  LED INTERNE SUR GPIO2 (CLIGNOTANTE DYNAMIQUE)
# ==========================================

output:
  - platform: gpio
    pin: GPIO2
    id: led_gpio2

switch:
  - platform: output
    output: led_gpio2
    id: led_bleue
    internal: true

interval:
  - id: clignotement_interval
    interval: 250ms # Démarre en clignotement rapide
    then:
      - switch.toggle: led_bleue

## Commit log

2026-04-17 FEAT : Ouverture du nombre de connexions maximales en Mode Access Point
2026-05-06 FEAT : Correction de la configuration des ports WebServer & WebSocket
    [Module_TIC.ino]
2026-05-07 FEAT : Changement du port WebSocket en 443 par défaut et reprise de la page de configuration pour une meilleure compérhension
2026-05-11 FEAT : Correction d'indentation du addWifiSpot() et incrément de version en v 0.2
    [Module_TIC.ino, common_utils.h]
2026-05-11 FEAT : Correction du message lorsque les clés de sécurité ne sont pas identiques
2026-08-28 FEAT: Suppression du boiter 3D et ajouts des Stickers en face du boitier
    [Locker.FCStd, Socle.FCStd, Supérieur.FCStd]
2026-09-09 FEAT : Intégration du Portail Captif de configuration
2026-09-15 FEAT : Ajout de la configuration du mode Historique ou Standard
2026-09-16 FEAT : Ajout des modes Historique et Standard dans le USER MANUAL
2026-09-16 FEAT : Reprise du container Configuration Compteur de la page de configuration
2026-09-16 FEAT : Intégration du fonctionnel des modes Historique et Standard avec un gros refactor du tic_extract
2026-09-18 FEAT : Ajout du dossier HOME_ASSISTANT permettant l'intégration des fichiers YAML compatibles Home Assistant
2026-09-21 Ajout des fichiers YAML
2026-09-21 Ajouts des fichiers YAML
2026-10-07 FEAT : Filtre de donnée TIC + Chunk
2026-10-12 FEAT : Ajout de la DATE
